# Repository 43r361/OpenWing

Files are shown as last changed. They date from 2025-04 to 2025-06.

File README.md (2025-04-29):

# OpenWing: DIY Quadcopter Project

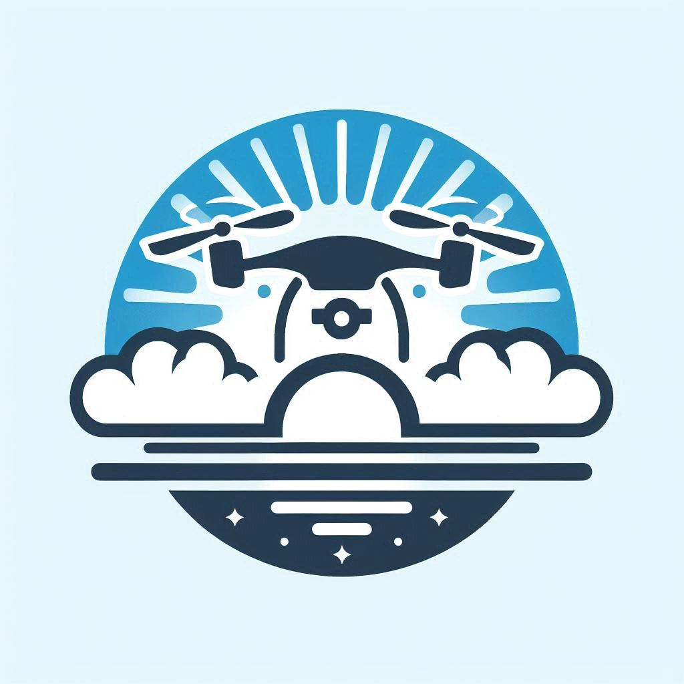
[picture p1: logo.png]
OpenWing Logo


OpenWing is a custom-built quadcopter designed and developed by Alexander Shestakov, Alexander Malinov, and Lora Apostolova as a VMKS assignment in TUES and TUES Fest 2025 project. This project showcases a quadcopter with a custom flight controller based on the ESP32 microcontroller, integrating various sensors and control systems for stable flight and precise maneuverability.

## Features

- **Custom Flight Controller**: Built using the ESP32, the flight controller handles sensor data processing, stabilization, and control.
- **Sensor Integration**:
  - MPU6050 for gyroscope and accelerometer data.
  - BMP085 for barometric pressure and altitude measurement.
  - HMC5883L for compass functionality.
- **Joystick Control**: A joystick interface for manual control of the quadcopter.
- **Kalman Filter**: Implements a Kalman filter for precise angle estimation and stabilization.
- **Testing Visualization**: A Python-based OpenGL application used for testing the quadcopter's orientation.

## Components

### Hardware

- **ESP32**: The core microcontroller for the flight controller.
- **MPU6050**: Gyroscope and accelerometer for motion sensing.
- **BMP085**: Barometric pressure sensor for altitude measurement.
- **HMC5883L**: Magnetometer for compass functionality.
- **Joysticks**: For manual control of the quadcopter.

### Software

- **Arduino Code**: Experimental snippets for sensor data processing and joystick control.
- **Python Testing Tool**: A Python script using OpenGL and Pygame for testing orientation data (code taken from [here](https://github.com/mattzzw/Arduino-mpu6050)).

## Acknowledgments

This project was made possible through the collaboration of Alexander Shestakov, Alexander Malinov, and Lora Apostolova. Special thanks to our school and mentors for their guidance and support.

## License

<p xmlns:cc="http://creativecommons.org/ns#" xmlns:dct="http://purl.org/dc/terms/"><a property="dct:title" rel="cc:attributionURL" href="https://github.com/43r361/OpenWing">OpenWing</a> by <a rel="cc:attributionURL dct:creator" property="cc:attributionName" href="https://github.com/43r361">Alexander Shestakov, Alexander Malinov and Lora Apostolova</a> is licensed under <a href="https://creativecommons.org/licenses/by-nc-sa/4.0/?ref=chooser-v1" target="_blank" rel="license noopener noreferrer" style="display:inline-block;">Creative Commons Attribution-NonCommercial-ShareAlike 4.0 International</a></p>

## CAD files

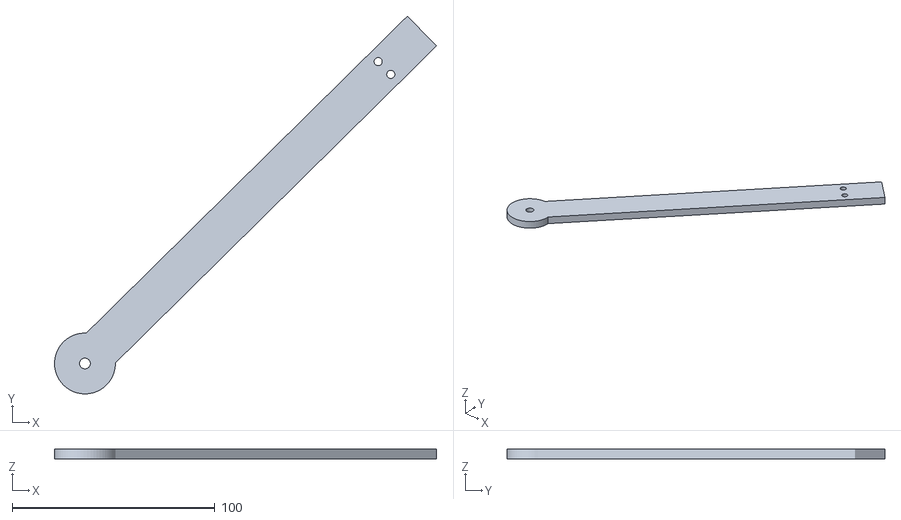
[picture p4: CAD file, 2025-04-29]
OpenWing Frame Pieces/Long side arm (1).stl
188.2 x 186.1 x 5.00

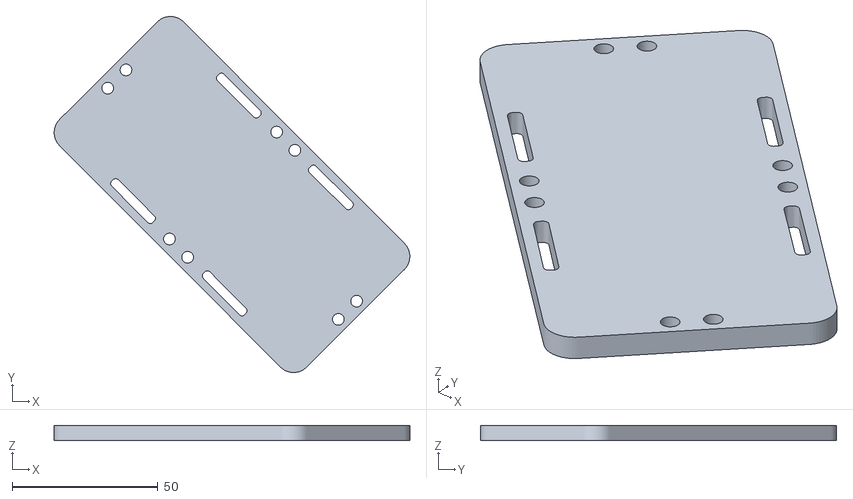
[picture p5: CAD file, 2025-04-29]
OpenWing Frame Pieces/Platform (1).stl
121.8 x 122.0 x 5.00

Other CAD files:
OpenWing Frame Pieces/Short side arm (1).stl

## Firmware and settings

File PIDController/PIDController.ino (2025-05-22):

#include <esp_now.h>
#include <WiFi.h>
#include <Adafruit_BMP085.h>
#include <HMC5883L_Simple.h>
#include <Wire.h>
#include "I2Cdev.h"
#include <ESP32Servo.h>  // ESP32Servo library installed by Library Manager

// sensor macros

#define I2C_SDA 41
#define I2C_SCL 42
#define RGB_PIN 48

#define LSB_PER_DEG_PER_SEC 65.5
#define LSB_PER_G 4096
#define CALIBRATION_CYCLES 2000

#define ESC_PIN1 (39)
#define ESC_PIN2 (38)

#define ESC_PIN3 (10)
#define ESC_PIN4 (9)

// in Hz
#define FREQUENCY (250)
// in s
#define PERIOD (1.0 / (float)FREQUENCY)

// throtle in ppm values
#define MIN_SPEED 1148  // 1148 | 1000 both values depend on the motor
#define MAX_SPEED 1832  // 1832

// sensor vals
float rateRoll = 0, ratePitch = 0, rateYaw = 0;
float angleRoll = 0, anglePitch = 0, angleYaw = 0;
// standard deviation on the initial angle: 2 deg
float kalmanAngleRoll = 0, kalmanUncertaintyAngleRoll = 2 * 2;
float kalmanAnglePitch = 0, kalmanUncertaintyAnglePitch = 2 * 2;

// index 0 is the angle prediction and index 1 is the uncertainty
float kalman1dOutput[] = { 0, 0 };

Servo motors[4];

uint32_t loopTimer = 0;

// in a cross or H motor configuration
// motor 1 front
// motor 2 right
// motor 3 bottom
// motor 4 left

// this type of controller expects the values to be in degrees per second
// range -70 - 70 degrees for yaw, roll and pitch
// range for throttle is 0 to 1
typedef struct
{
  float roll;
  float yaw;
  float pitch;
  float throttle;
} struct_message;

typedef struct
{
  float P;
  float I;
  float D;
} pid_constants_t;

typedef struct
{
  float Pitch;
  float Roll;
  float Yaw;
} angle_val_t;

typedef struct
{
  float Iterm;
  float Error;
  float PIDOutput;
} pid_return_t;

pid_constants_t rateRollPID = { 0.6, 3.5, 0.03 };
pid_constants_t ratePitchPID = { 0.6, 3.5, 0.03 };
pid_constants_t rateYawPID = { 2, 12, 0 };

angle_val_t ErrorRate = { 0, 0, 0 };
angle_val_t PreviousErrorRate = { 0, 0, 0 };
angle_val_t PreviousItermRate = { 0, 0, 0 };


angle_val_t ErrorAngle = { 0, 0, 0 };
angle_val_t PreviousErrorAngle = { 0, 0, 0 };
angle_val_t PreviousItermAngle = { 0, 0, 0 };

pid_constants_t angleRollPID = { 2, 0, 0 };
pid_constants_t anglePitchPid = { 2, 0, 0 };

struct_message controllerVals = { 0, 0, 0, 0 };

void OnDataRecv(const uint8_t *mac, const uint8_t *incomingData, int len) {
  memcpy(&controllerVals, incomingData, sizeof(controllerVals));
  Serial.print("Bytes received: ");
  Serial.println(len);
  Serial.print("Roll: ");
  Serial.println(controllerVals.roll);
  Serial.print("Pitch: ");
  Serial.println(controllerVals.pitch);
  Serial.print("Yaw: ");
  Serial.println(controllerVals.yaw);
  Serial.print("Throttle: ");
  Serial.print(controllerVals.throttle);
  Serial.println();
}

pid_return_t pid_equation(float Error, pid_constants_t PID_const, float PreviousError, float PreviousIterm) {
  float Pterm = PID_const.P * Error;
  float Iterm = PreviousIterm + PID_const.I * (Error + PreviousError) * PERIOD;

  // use to avoid integral wind up
  if (Iterm > 400)
    Iterm = 400;
  else if (Iterm < -400)
    Iterm = -400;

  float Dterm = PID_const.D * (Error - PreviousError) / PERIOD;
  float PIDOutput = Pterm + Iterm + Dterm;
  // limit to -400  400
  if (PIDOutput > 400)
    PIDOutput = 400;
  else if (PIDOutput < -400)
    PIDOutput = -400;

  pid_return_t output;
  output.Iterm = Iterm;
  output.Error = Error;
  output.PIDOutput = PIDOutput;
  return output;
}

void reset_pid() {
  PreviousErrorRate.Pitch = 0;
  PreviousErrorRate.Roll = 0;
  PreviousErrorRate.Yaw = 0;
  PreviousItermRate.Pitch = 0;
  PreviousItermRate.Roll = 0;
  PreviousItermRate.Yaw = 0;

  PreviousErrorAngle.Roll = 0;
  PreviousErrorAngle.Pitch = 0;

  PreviousItermAngle.Roll = 0;
  PreviousItermAngle.Pitch = 0;
}

void motor_setup() {
  pinMode(ESC_PIN1, OUTPUT);
  pinMode(ESC_PIN2, OUTPUT);
  pinMode(ESC_PIN3, OUTPUT);
  pinMode(ESC_PIN4, OUTPUT);
  motors[0].attach(ESC_PIN1);
  motors[1].attach(ESC_PIN2);
  motors[2].attach(ESC_PIN3);
  motors[3].attach(ESC_PIN4);

  delay(3000);
  for (int i = 0; i < 4; i++) {
    motors[i].writeMicroseconds(1400);
  }
  delay(1000);
  for (int i = 0; i < 4; i++) {
    motors[i].writeMicroseconds(MIN_SPEED);
  }
  delay(3500);
  Serial.println("Available for input!");
}

void setup() {
  Serial.begin(115200);
  rgbLedWrite(RGB_PIN, RGB_BRIGHTNESS, 0, 0);  // Red

  WiFi.mode(WIFI_MODE_STA);

  if (esp_now_init() != ESP_OK) {
    Serial.println("Error initializing ESP-NOW");
    return;
  }
  esp_now_register_recv_cb(esp_now_recv_cb_t(OnDataRecv));

  sensor_setup();

  motor_setup();

  // avoid accidental lift
  while (controllerVals.throttle < 0.10) {
    delay(4);
  }
  // indicate that setup is done
  rgbLedWrite(RGB_PIN, 0, RGB_BRIGHTNESS, 0);  // Green
}

float throttle_to_input(float throttle) {
  return (MAX_SPEED - MIN_SPEED) * throttle + MIN_SPEED;
}

float input_to_throttle(float input) {
  return (input - MIN_SPEED) / (MAX_SPEED - MIN_SPEED);
}

void loop() {

  readAll();

  // calculate the roll and pitch angles
  kalman1d(kalmanAngleRoll, kalmanUncertaintyAngleRoll, rateRoll, angleRoll);
  kalmanAngleRoll = kalman1dOutput[0];
  kalmanUncertaintyAngleRoll = kalman1dOutput[1];

  kalman1d(kalmanAnglePitch, kalmanUncertaintyAnglePitch, ratePitch, anglePitch);
  kalmanAnglePitch = kalman1dOutput[0];
  kalmanUncertaintyAnglePitch = kalman1dOutput[1];

  angleYaw += rateYaw * PERIOD;

  if (angleYaw >= 360) {
    angleYaw -= 360;
  }

  angle_val_t DesiredAngle = {.Pitch =controllerVals.pitch, .Roll=controllerVals.roll, .Yaw = 0};
  ErrorAngle.Roll=DesiredAngle.Roll - kalmanAngleRoll;
  ErrorAngle.Pitch=DesiredAngle.Pitch - kalmanAnglePitch;

  pid_return_t rollAngleReturn = pid_equation(ErrorAngle.Roll, angleRollPID, PreviousErrorAngle.Roll, PreviousItermAngle.Roll);
  pid_return_t rollPitchReturn = pid_equation(ErrorAngle.Pitch, anglePitchPid, PreviousErrorAngle.Pitch, PreviousItermAngle.Pitch);

  angle_val_t DesiredRate = {0,0,0};
  // update error
  PreviousErrorAngle.Roll = rollAngleReturn.Error;
  PreviousErrorAngle.Pitch = rollPitchReturn.Error;
  //update Iterm
  PreviousItermAngle.Roll = rollAngleReturn.Iterm;
  PreviousItermAngle.Pitch = rollPitchReturn.Iterm;
  //desired values
  DesiredRate.Roll=rollAngleReturn.PIDOutput;
  DesiredRate.Pitch=rollPitchReturn.PIDOutput;


  // printKalmanAngles();

  ErrorRate.Roll = DesiredRate.Roll - rateRoll;
  ErrorRate.Pitch = DesiredRate.Pitch - ratePitch;
  ErrorRate.Yaw = controllerVals.yaw - rateYaw;

  pid_return_t rollReturn = pid_equation(ErrorRate.Roll, rateRollPID, PreviousErrorRate.Roll, PreviousItermRate.Roll);
  pid_return_t pitchReturn = pid_equation(ErrorRate.Pitch, ratePitchPID, PreviousErrorRate.Pitch, PreviousItermRate.Pitch);
  pid_return_t yawReturn = pid_equation(ErrorRate.Yaw, rateYawPID, PreviousErrorRate.Yaw, PreviousItermRate.Yaw);
  // update error
  PreviousErrorRate.Roll = rollReturn.Error;
  PreviousErrorRate.Pitch = pitchReturn.Error;
  PreviousErrorRate.Yaw = yawReturn.Error;
  // update Iterm
  PreviousItermRate.Roll = rollReturn.Iterm;
  PreviousItermRate.Pitch = pitchReturn.Iterm;
  PreviousItermRate.Yaw = yawReturn.Iterm;

  float InputPitch = pitchReturn.PIDOutput;  // in direct input
  float InputRoll = rollReturn.PIDOutput;
  float InputYaw = yawReturn.PIDOutput;

  // limit throttle
  controllerVals.throttle = min(0.8f, controllerVals.throttle);
  float InputThrottle = throttle_to_input(controllerVals.throttle);

  float input[4];
  // 0.00 - 0.25;
  // This is for a H or Cross motor position

  // inputPerc[0]=myData.throttle-myData.pitch-myData.yaw;
  // inputPerc[1]=myData.throttle-myData.roll+myData.yaw;
  // inputPerc[2]=myData.throttle+myData.pitch-myData.yaw;
  // inputPerc[3]=myData.throttle+myData.roll+myData.yaw;

  // InputYaw = 0;
  input[0] = InputThrottle - InputPitch + InputYaw;  // to show basic control
  input[1] = InputThrottle - InputRoll - InputYaw;
  input[2] = InputThrottle + InputPitch + InputYaw;
  input[3] = InputThrottle + InputRoll - InputYaw;

  for (int i = 0; i < 4; i++) {
    // limit so the motors don't stop
    input[i] = max(input[i], throttle_to_input(0.10f));  // 0.10 should be 0.20 used for showcasing
    // stop it from exeding max limit
    input[i] = min(input[i], throttle_to_input(0.80f));  // should be 1.00 but 0.60 is used for showcasing
  }

  // stop the motor if the values are low
  if (controllerVals.throttle < 0.04) {
    for (int i = 0; i < 4; i++) {
      input[i] = MIN_SPEED;
    }
    reset_pid();
  } else {
    for (int i = 0; i < 4; i++) {
      motors[i].writeMicroseconds(round(input[i]));
    }
  }

  // do nothing until it's time for the next loop (every [PERIOD] seconds)
  while (micros() - loopTimer < PERIOD * 1000000)
    ;
  loopTimer = micros();
}

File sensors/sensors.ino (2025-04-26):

#include <Adafruit_BMP085.h>
#include <HMC5883L_Simple.h>
#include <Wire.h>

#include "I2Cdev.h"

Adafruit_BMP085 bmp;
HMC5883L_Simple compass;

#define I2C_SDA 21
#define I2C_SCL 22

#define LSB_PER_DEG_PER_SEC 65.5
#define LSB_PER_G 4096
#define CALIBRATION_CYCLES 2000
// in Hz
#define FREQUENCY (250)
// in s
#define PERIOD (1.0 / (float)FREQUENCY)

float rateRoll = 0, ratePitch = 0, rateYaw = 0;
float rateCalibrationRoll = 0, rateCalibrationPitch = 0, rateCalibrationYaw = 0;
bool calibrated = false;

float accX = 0, accY = 0, accZ = 0;
// these values can be set to fix offsets in the accelerometer readings
float accCalibrationX = 0, accCalibrationY = 0, accCalibrationZ = 0;
float angleRoll = 0, anglePitch = 0, angleYaw = 0;

uint32_t loopTimer;

// standard deviation on the initial angle: 2 deg
float kalmanAngleRoll = 0, kalmanUncertaintyAngleRoll = 2 * 2;
float kalmanAnglePitch = 0, kalmanUncertaintyAnglePitch = 2 * 2;

// index 0 is the angle prediction and index 1 is the uncertainty
float kalman1dOutput[] = {0, 0};

// state - angle calculated with kalman
// input - rotation rate
// measurement - accelerometer angle
// why constants?
void kalman1d(float state, float uncertainty, float input, float measurement) {
    // predict the current state of the system
    state += PERIOD * input;

    // calculate the uncertainty
    uncertainty += PERIOD * PERIOD * 4 * 4;

    // calculate the kalman gain based on previous calculations
    float gain = uncertainty / (uncertainty + 3 * 3);

    // update the predicted state
    state += gain * (measurement - state);

    // update the uncertainty
    uncertainty *= 1 - gain;

    // set the output
    kalman1dOutput[0] = state;
    kalman1dOutput[1] = uncertainty;
}

void printRates() {
    // Serial.println("Rates:");
    Serial.print(rateRoll);
    Serial.print(", ");
    Serial.print(ratePitch);
    Serial.print(", ");
    Serial.println(rateYaw);
}

void printAcceleration() {
    // Serial.println("Acceleration:");
    Serial.print(accX);
    Serial.print(", ");
    Serial.print(accY);
    Serial.print(", ");
    Serial.println(accZ);
}

void printAngles() {
    // Serial.println("Angles:");
    Serial.print(angleRoll);
    Serial.print(", ");
    Serial.print(anglePitch);
    Serial.print(", ");
    Serial.println(angleYaw);
}

void printKalmanAngles() {
    // Serial.println("Kalman angles:");
    Serial.print(kalmanAngleRoll);
    Serial.print(", ");
    Serial.print(-kalmanAnglePitch);
    Serial.print(", ");
    Serial.println(angleYaw);
}

void readAccelerometer() {
    // access the registers, storing the accelerometer values
    Wire.beginTransmission(0x68);
    Wire.write(0x3B);
    Wire.endTransmission();

    // read register 0x3B-0x40 (59-64), containing measurements
    Wire.requestFrom(0x68, 6);

    // the data for x, y and z is contained in 2 registers each
    // that's why we need two reads for each value (and a shift)
    int16_t accXLSB = Wire.read() << 8 | Wire.read();
    int16_t accYLSB = Wire.read() << 8 | Wire.read();
    int16_t accZLSB = Wire.read() << 8 | Wire.read();

    // convert the measurements from LSB to g
    accX = (float)accXLSB / LSB_PER_G + accCalibrationX;
    accY = (float)accYLSB / LSB_PER_G + accCalibrationY;
    accZ = (float)accZLSB / LSB_PER_G + accCalibrationZ;

    // calculate angles
    angleRoll = atan(accY / sqrt(accX * accX + accZ * accZ)) * RAD_TO_DEG;
    // idk if we should have a "-" in front (seems wrong)
    anglePitch = -atan(accX / sqrt(accY * accY + accZ * accZ)) * RAD_TO_DEG;
}

void readGyro() {
    // access the registers, storing the gyroscope values
    Wire.beginTransmission(0x68);
    Wire.write(0x43);
    Wire.endTransmission();

    // read registers 0x43-0x48 (67-72), containing measurements
    Wire.requestFrom(0x68, 6);

    // the data for x, y and z is contained in 2 registers each
    // that's why we need two reads for each value (and a shift)
    int16_t rateXLSB = Wire.read() << 8 | Wire.read();
    int16_t rateYLSB = Wire.read() << 8 | Wire.read();
    int16_t rateZLSB = Wire.read() << 8 | Wire.read();

    // convert the measurements from LSB to deg/s
    rateRoll = (float)rateXLSB / LSB_PER_DEG_PER_SEC;
    ratePitch = (float)rateYLSB / LSB_PER_DEG_PER_SEC;
    rateYaw = (float)rateZLSB / LSB_PER_DEG_PER_SEC;

    if (calibrated) {
        rateRoll -= rateCalibrationRoll;
        ratePitch -= rateCalibrationPitch;
        rateYaw -= rateCalibrationYaw;
    }
}

void readAll() {
    readAccelerometer();
    readGyro();
}

void bootGy87() {
    // start the mpu6050
    Wire.beginTransmission(0x68);
    Wire.write(0x6B);
    Wire.write(0x00);
    Wire.endTransmission();

    // configure the accelerometer's full scale range (4096 LSB/g)
    Wire.beginTransmission(0x68);
    Wire.write(0x1C);
    Wire.write(0x10);
    Wire.endTransmission();

    // activate the gyroscope's low pass filter (reduces vibration noise)
    Wire.beginTransmission(0x68);
    Wire.write(0x1A);
    Wire.write(0x05);
    Wire.endTransmission();

    // configure the gyroscope's full scale range (65.5 LSB/deg/s)
    Wire.beginTransmission(0x68);
    Wire.write(0x1B);
    Wire.write(0x8);
    Wire.endTransmission();

    // calibrate the gyroscope
    Serial.println("Start calibration");

    for (int i = 0; i < CALIBRATION_CYCLES; i++) {
        readGyro();

        rateCalibrationRoll += rateRoll;
        rateCalibrationPitch += ratePitch;
        rateCalibrationYaw += rateYaw;

        delay(1);
    }

    rateCalibrationRoll /= CALIBRATION_CYCLES;
    rateCalibrationPitch /= CALIBRATION_CYCLES;
    rateCalibrationYaw /= CALIBRATION_CYCLES;

    calibrated = true;

    Serial.println("Calibration finished\nValues:");
    Serial.print(rateCalibrationRoll);
    Serial.print(", ");
    Serial.print(rateCalibrationPitch);
    Serial.print(", ");
    Serial.println(rateCalibrationYaw);
    Serial.println("End");
}

void setup() {
    Serial.begin(115200);

    // set the clock speed to 400 kHz
    Wire.begin(I2C_SDA, I2C_SCL, 400000);

    // give the mpu6050 time to start
    delay(250);

    bootGy87();

    // initialize bmp085
    if (!bmp.begin()) {
        Serial.println("Could not find a valid BMP085 sensor, check wiring!");
        while (1) {
        }
    }

    // initialize hmc5883l
    compass.SetDeclination(23, 35, 'E');
    compass.SetSamplingMode(COMPASS_SINGLE);
    compass.SetScale(COMPASS_SCALE_130);
    compass.SetOrientation(COMPASS_HORIZONTAL_X_NORTH);
}
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

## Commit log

2025-04-05 first iteration of code for sensors
2025-04-05 added a python program found online to visualize the sensor measurements
2025-04-05 changed code for the sensors to measure more accurately with less errors cleaned the code up removed unused functions
    [sensors.ino]
2025-04-19 added a program to get an ESP32's MAC address which is used in ESP NOW communication
2025-04-19 Added basic motor control
2025-04-22 Added seperate motor code and fixed some comments
    [receiver.ino, working_motor.ino]
2025-04-22 Added Fpv drone pid controller
2025-04-23 fixed an issue with mapping values from the joystick
    [boxctrl_6d0f_imu.py, transmitter.ino]
2025-04-26 reorganized part of the sensors code reduced transmitter frequency to fix heat issues
    [sensors.ino, transmitter.ino]
2025-04-29 Add files via upload
    Frame pieces CAD files
    [Long side arm (1).stl, Platform (1).stl, Short side arm (1).stl]
2025-04-29 Frame Pieces
    [Long side arm (1).stl, Platform (1).stl, Short side arm (1).stl]
2025-04-30 Added small fixes and improvements to controller
    [PIDController.ino]
2025-05-22 synchronised sensors.ino in advancded controller to match shestakovs
